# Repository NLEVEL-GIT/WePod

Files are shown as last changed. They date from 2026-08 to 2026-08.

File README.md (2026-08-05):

# WePod

Wepod is Our Ipod, it is an open source MP3 Player that uses the Xiao RP2040

PS: All images of the PCB, CAD and Schematics are on the assets folder if u wanna see.

## Features:
- 1.3 Inch TFT Display
- 5 Button
- SD Card Reader
- 3.5mm Jack
- Powered by any 5V Supply using the dedicated pads

## CAD Model:
Everything fits in a sandwich kind of way by stacking the bottom and top case parts and inbetween the PCB. It requires 4 M3x3 brass inserts and 4 15mm M3 Screws.
It has 3 different printed pieces. The Bottom part of the case where everything will sit in. The Top part that locks everything and the Butons (5 Needed).
Made in Fusion360 cuz its free.

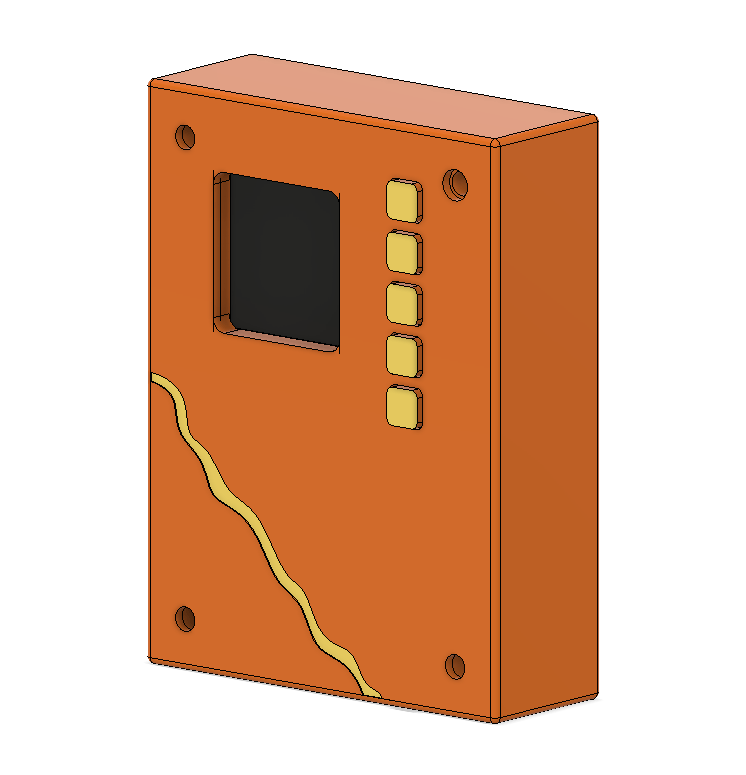
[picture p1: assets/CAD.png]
WePod 3D Render


## PCB
It was made in KiCad. Only needing to add Kicad Care package Symbols and Footprints for the Xiao RP2040 and a bunch of other symbols found in SnapEDA.
All 3D models were found on GrabCad

**Schematic:**
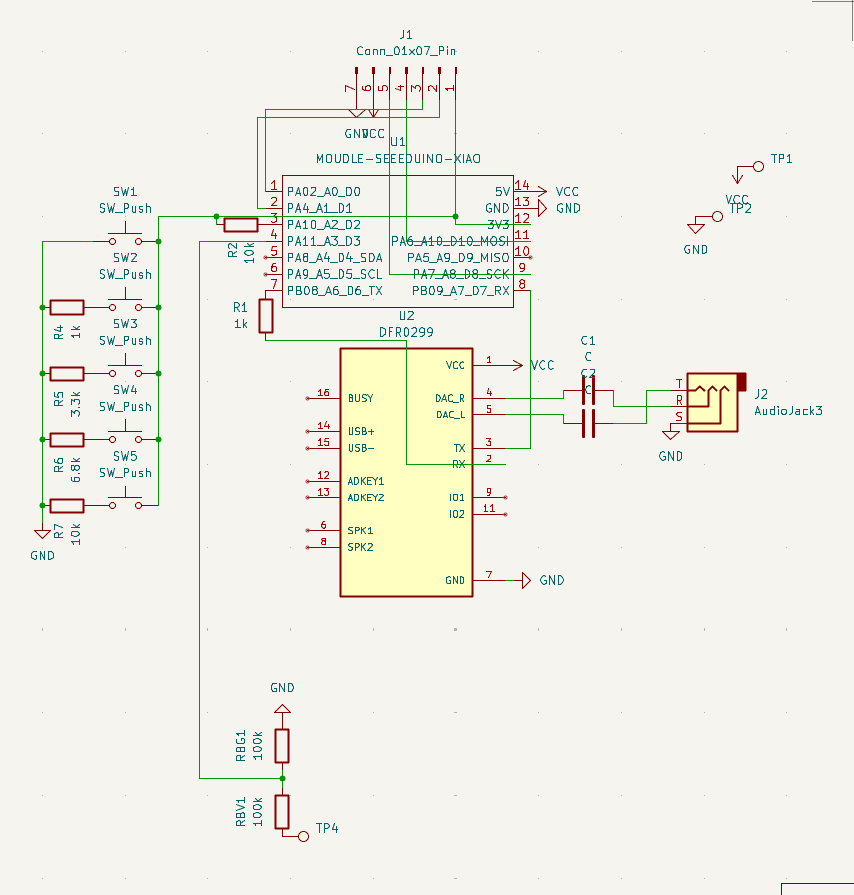
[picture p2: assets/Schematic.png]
WePod Schematic


**PCB Layout:**
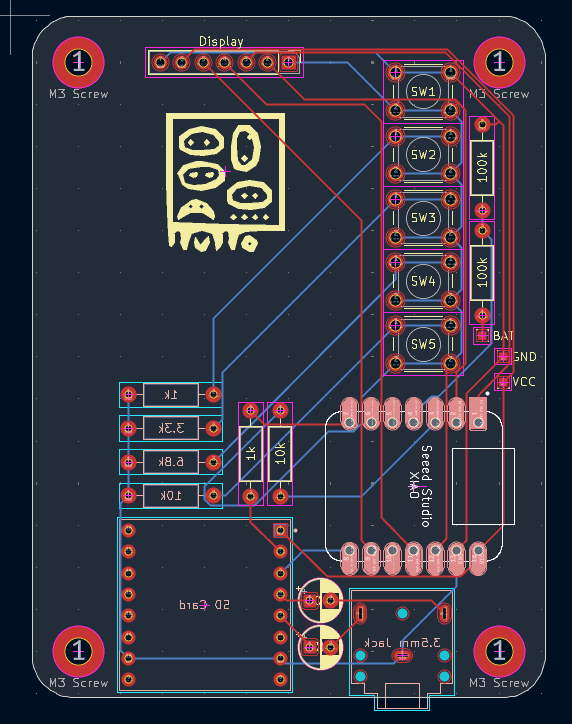
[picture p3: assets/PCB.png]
WePod PCB Layout


## Firmware Overview
The WePod uses C++ as its language of choice and it was made with the help of generative AI since im not really good at coding.

## BOM:
Here should be everything you need to make this hackpad

- 1.3 Inch TFT display
- DFPlayer
- 3.5mm Jack
- 5x 6x6mm buttons
- 1x XIAO RP2040
- 1x Case (3 printed parts)
- A Bunch of Resistors (1k, 3.3k, 6.8k, 10k and 100k)
- 2x 10uf Capacitors

## Extra stuff
This was my first Original project since my first was the MacroPad so not using a siplified code made me want to die. Conclusion: Hardware is life and coding Sucks

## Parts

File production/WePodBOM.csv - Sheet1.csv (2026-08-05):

Item Name | Qty | Price (total) (USD) (Conversion from Euro) | Item link | Notes
Seeed Studio Xiao RP2040 | 1 | $6.47 | https://mauser.pt | All items are from PT stores and have been converted from euro to dollar since I live in Portugal
1.3 Inch TFT Display | 1 | $5.22 | https://aliexpress.com
3.5mm Jack | 1 | $0.25 | https://www.digikey.pt
DFPlayer | 1 | $2.29 | https://aliexpress.com
Resistor Pack | 1 | $2,65 | https://aliexpress.com | This pack was choosen since it makes me save money by going over the necessary buy amount for the free shipping
10 uF Capacitors | 2 | $0.53 | https://mauser.pt | These were choosent since i only have 8mm of clearance between plates to fir the capacitors
6x6mm Buttons | 5 | $0.81 | https://mauser.pt
MH-CD42 + 5V Buck Converter | 1 | $2.48 | https://aliexpress.com | This price is the combined price of the actual product and its forced shipping of 1.45 euros since its a global seller
800mah Lipo battery | 1 | $6.58 | https://mauser.pt
Switch | 1 | $0.46 | https://www.aquario.pt
PCB | 1 | $5.11 | https://www.jlcpcb.com
Total Price (USD): | $30.20

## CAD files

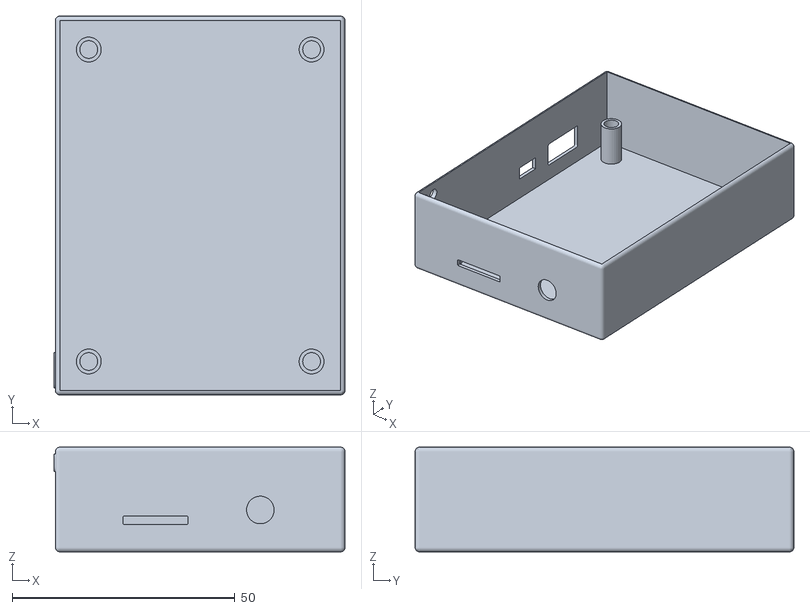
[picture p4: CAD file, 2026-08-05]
production/Bottom Case.stl
65.3 x 85.0 x 23.5

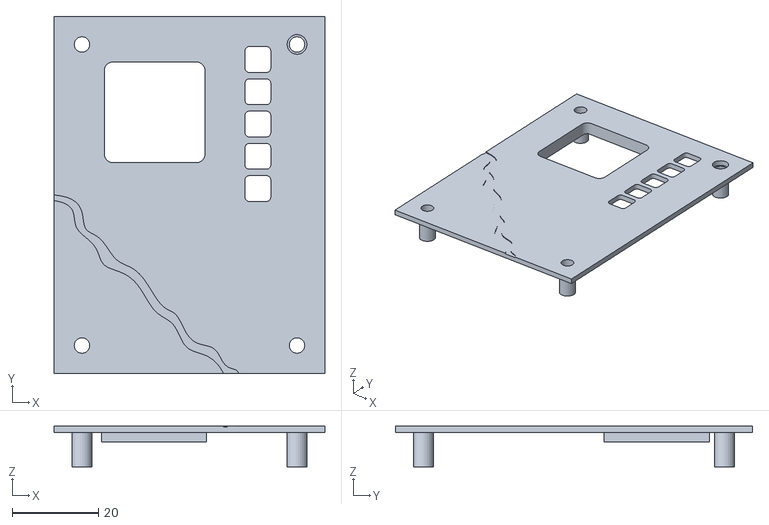
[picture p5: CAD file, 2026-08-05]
production/Top Case.stl
63.0 x 83.0 x 9.49

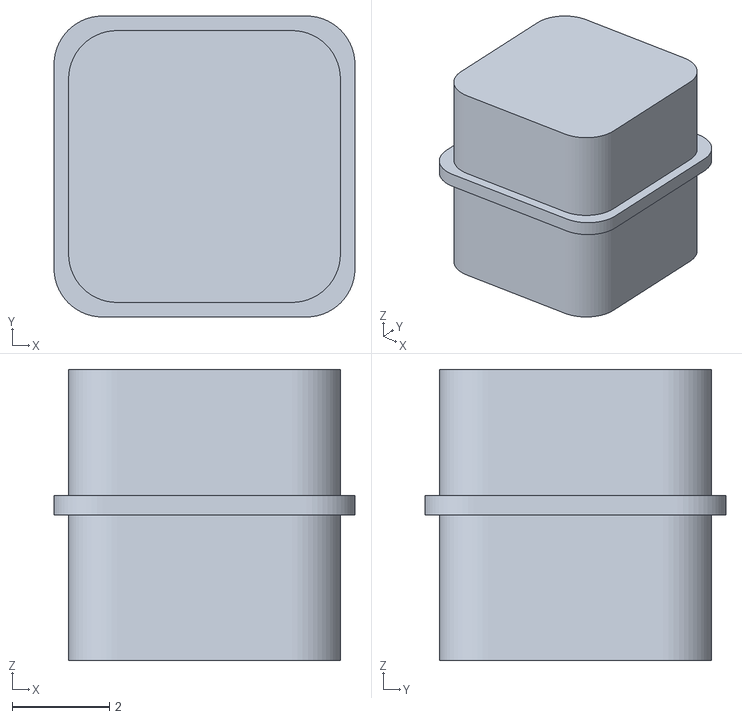
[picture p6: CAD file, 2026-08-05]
production/Button.stl
6.20 x 6.20 x 6.00

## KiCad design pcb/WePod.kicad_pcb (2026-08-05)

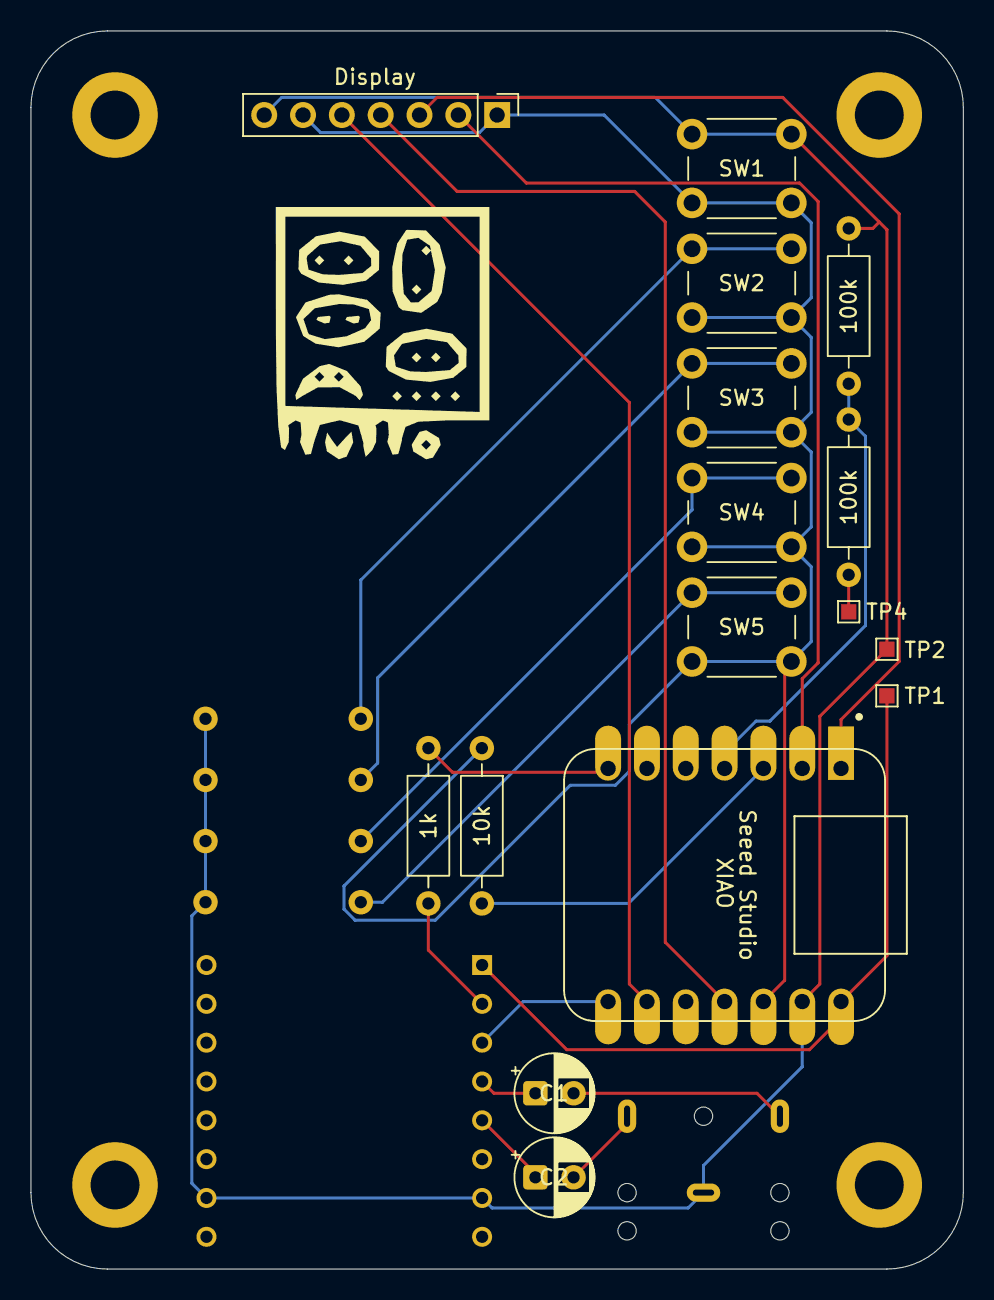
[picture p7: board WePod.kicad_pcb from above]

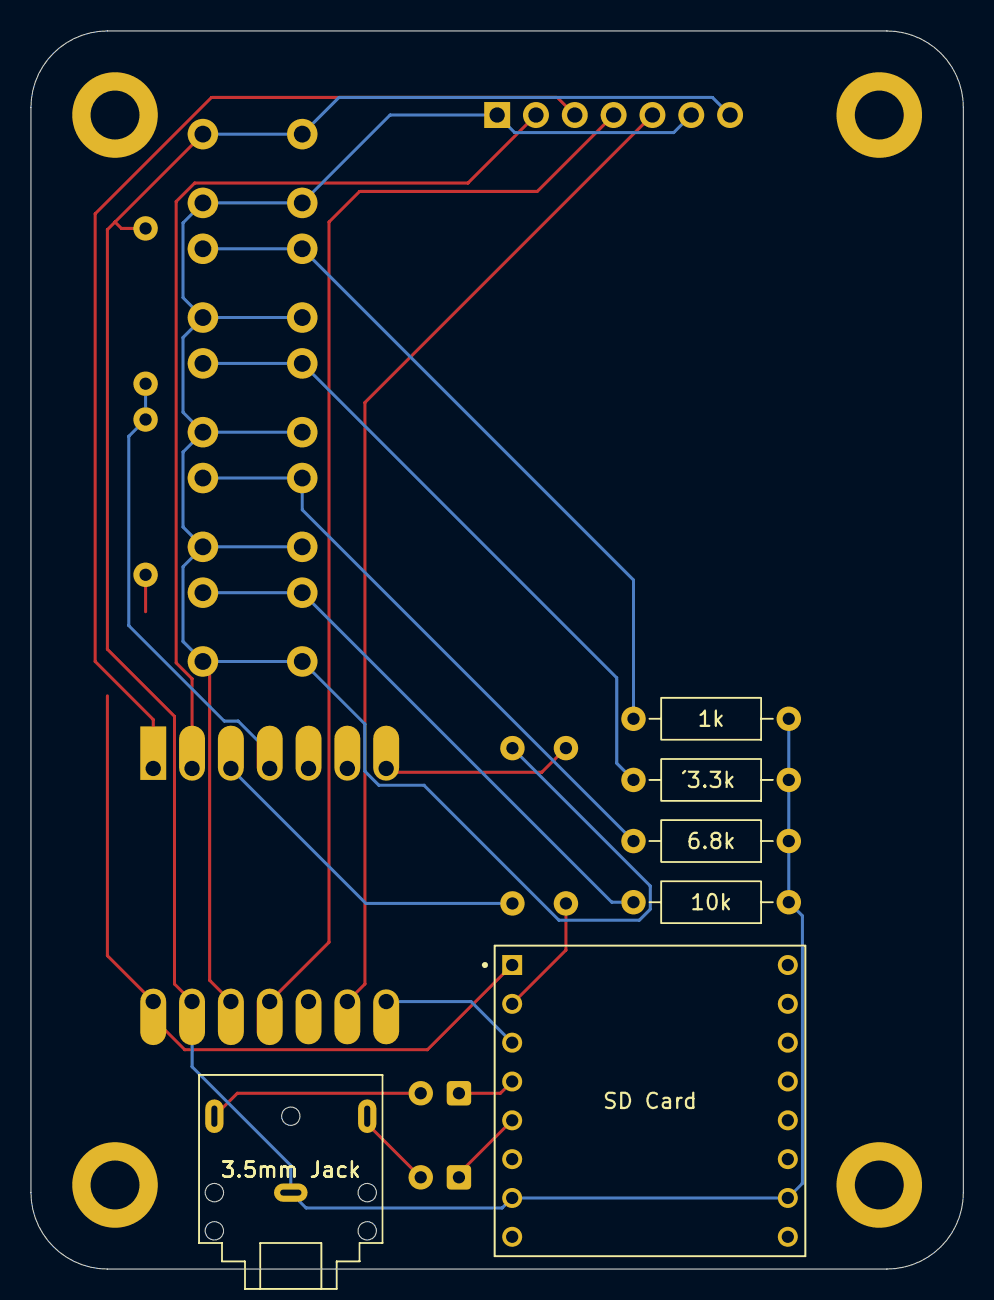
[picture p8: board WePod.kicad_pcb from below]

Board: 2 copper layers, 61.0 x 81.0 mm, 22 parts (6 on the bottom side), 21 nets.

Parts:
1k, 1k#2: 1k; R_Axial_DIN0207_L6.3mm_D2.5mm_P10.16mm_Horizontal
3.5mm Jack: 3.5mm Jack; Jack_3.5mm_CUI_SJ1-3523N_Horizontal
6.8k: 6.8k; R_Axial_DIN0207_L6.3mm_D2.5mm_P10.16mm_Horizontal
10k, 10k#2: 10k; R_Axial_DIN0207_L6.3mm_D2.5mm_P10.16mm_Horizontal
100k, 100k#2: 100k; R_Axial_DIN0207_L6.3mm_D2.5mm_P10.16mm_Horizontal
C1, C2: C; CP_Radial_D5.0mm_P2.50mm
J1: Display; PinHeader_1x07_P2.54mm_Vertical
SW1, SW2, SW3, SW4, SW5: SW_Push; SW_PUSH_6mm
TP1, TP2, TP4: TestPoint; TestPoint_Pad_1.0x1.0mm
U1: MOUDLE-SEEEDUINO-XIAO; XIAO-Generic-Hybrid-14P-2.54-21X17.8MM
U2: SD Card; MODULE_DFR0299
´3.3k: 3.3k; R_Axial_DIN0207_L6.3mm_D2.5mm_P10.16mm_Horizontal

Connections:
GND: 1k#2.1, 3.5mm Jack.S, 6.8k.1, 10k#2.1, 100k#2.2, J1.7, SW1.1, TP2.1 (1_1), U1.13 (GND), U2.7 (GND), U2.10 (GND), ´3.3k.1
unnamed: 3.5mm Jack.R, C1.2
unnamed: 3.5mm Jack.T, C2.2
unnamed: 10k.1, J1.1, J1.6, SW1.2, SW2.2, SW3.2, SW4.2, SW5.2, U1.12 (3V3)
unnamed: J1.2, U1.2 (PA4_A1_D1)
unnamed: J1.3, U1.1 (PA02_A0_D0)
unnamed: J1.4, U1.11 (PA6_A10_D10_MOSI)
unnamed: J1.5, U1.9 (PA7_A8_D8_SCK)
unnamed: 1k#2.2, SW2.1
unnamed: SW3.1, ´3.3k.2
unnamed: 6.8k.2, SW4.1
unnamed: 10k#2.2, SW5.1
unnamed: 100k.1, TP4.1 (1_1)
unnamed: 10k.2, U1.3 (PA10_A2_D2)
unnamed: 100k.2, 100k#2.1, U1.4 (PA11_A3_D3)
unnamed: 1k.1, U1.7 (PB08_A6_D6_TX)
unnamed: U1.8 (PB09_A7_D7_RX), U2.3 (TX)
unnamed: C2.1, U2.5 (DAC_L)
unnamed: C1.1, U2.4 (DAC_R)
unnamed: 1k.2, U2.2 (RX)
VCC: TP1.1 (1_1), U1.14 (5V), U2.1 (VCC)

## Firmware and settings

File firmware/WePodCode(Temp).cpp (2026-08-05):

#include <Arduino.h>                //If the code breaks sry i cant code well and gemini helped a bunch so blame it on him
#include <DFRobotDFPlayerMini.h>
#include <TFT_eSPI.h> 

const int PIN_BTN_LADDER = A2;   
const int PIN_BATTERY_ADC = A3;  

const int VAL_SELECT   = 100; //change this crap when i get the actual stuff cuz resistors are funny 
const int VAL_DOWN     = 300; //change this crap when i get the actual stuff cuz resistors are funny 
const int VAL_UP       = 500; //change this crap when i get the actual stuff cuz resistors are funny  
const int VAL_VOL_UP   = 700; //change this crap when i get the actual stuff cuz resistors are funny 
const int VAL_VOL_DOWN = 900; //change this crap when i get the actual stuff cuz resistors are funny 
const int ADC_TOLERANCE = 50; //change this crap when i get the actual stuff cuz resistors are funny  

enum Button { BTN_NONE, BTN_SELECT, BTN_DOWN, BTN_UP, BTN_VOL_UP, BTN_VOL_DOWN }; //No Digital Situation

TFT_eSPI tft = TFT_eSPI(); 
DFRobotDFPlayerMini myDFPlayer;

Button currentButton = BTN_NONE;
Button lastButton = BTN_NONE;
unsigned long lastDebounceTime = 0;
const int debounceDelay = 50; 
unsigned long selectPressTimer = 0; 

bool inMenuMode = true; 
bool isPlaying = false;
int currentVolume = 15; 
unsigned long lastBatteryCheck = 0;
int currentBatteryPercent = 0;

int currentFolderIndex = 1;  
int currentSongIndex = 1;    
int selectedListItem = 0;    

// Content Setup 
String folderName = "FOLDER 01";
const int numSongsInFolder = 2; 
String songNames[numSongsInFolder] = {"SONG A", "SONG B"};

Button getPressedButton() {
  int val = analogRead(PIN_BTN_LADDER);
  if (abs(val - VAL_SELECT) < ADC_TOLERANCE)   return BTN_SELECT;
  if (abs(val - VAL_DOWN) < ADC_TOLERANCE)     return BTN_DOWN;
  if (abs(val - VAL_UP) < ADC_TOLERANCE)       return BTN_UP;
  if (abs(val - VAL_VOL_UP) < ADC_TOLERANCE)   return BTN_VOL_UP;
  if (abs(val - VAL_VOL_DOWN) < ADC_TOLERANCE) return BTN_VOL_DOWN;
  return BTN_NONE; 
}

void setup() {
  Serial.begin(115200);
  
  randomSeed(micros()); //Gambling

  tft.init();
  tft.setRotation(1); 
  tft.fillScreen(TFT_BLACK);
  tft.setTextColor(TFT_WHITE, TFT_BLACK); 
  tft.setTextSize(2);
  tft.setCursor(10, 10);
  tft.println("Booting OS...");

  Serial1.begin(9600);
  if (!myDFPlayer.begin(Serial1)) {
    tft.setTextColor(TFT_RED, TFT_BLACK);
    tft.println("Audio Error!");
    while(true); 
  }

  myDFPlayer.volume(currentVolume);
  updateScreenUI(); 
}

void loop() {

  Button reading = getPressedButton();
  Button pressedThisFrame = BTN_NONE; 

  if (reading != lastButton) lastDebounceTime = millis();
  if ((millis() - lastDebounceTime) > debounceDelay) {
    if (reading != currentButton) {
      currentButton = reading;
      if (currentButton != BTN_NONE) pressedThisFrame = currentButton;
    }
  }
  lastButton = reading;

  if (currentButton == BTN_SELECT && !inMenuMode) {            // Too lazy for 6th button
    if (selectPressTimer == 0) selectPressTimer = millis();
    if (millis() - selectPressTimer > 1000) { 
      inMenuMode = true; 
      selectPressTimer = 0; 
      updateScreenUI();
    }
  } else {
    selectPressTimer = 0; 
  }

  if (inMenuMode) {
    if (pressedThisFrame == BTN_SELECT) {
      inMenuMode = false; 
      currentSongIndex = selectedListItem + 1; 
      myDFPlayer.playFolder(currentFolderIndex, currentSongIndex);
      isPlaying = true;
      updateScreenUI();
    }
    if (pressedThisFrame == BTN_DOWN && selectedListItem < numSongsInFolder - 1) {
      selectedListItem++;
      updateScreenUI();
    }
    if (pressedThisFrame == BTN_UP && selectedListItem > 0) {
      selectedListItem--;
      updateScreenUI();
    }
  } 

  else {
    if (pressedThisFrame == BTN_SELECT) {
      isPlaying = !isPlaying;
      if (isPlaying) myDFPlayer.start();
      else myDFPlayer.pause();
      updateScreenUI(); 
    }
    if (pressedThisFrame == BTN_DOWN && currentSongIndex < numSongsInFolder) {
      currentSongIndex++;
      myDFPlayer.playFolder(currentFolderIndex, currentSongIndex);
      isPlaying = true;
      updateScreenUI();
    }
    if (pressedThisFrame == BTN_UP && currentSongIndex > 1) {
      currentSongIndex--;
      myDFPlayer.playFolder(currentFolderIndex, currentSongIndex);
      isPlaying = true;
      updateScreenUI();
    }
  }

  if (pressedThisFrame == BTN_VOL_UP && currentVolume < 30) {
    currentVolume++;
    myDFPlayer.volume(currentVolume);
    updateScreenUI(); 
  }
  if (pressedThisFrame == BTN_VOL_DOWN && currentVolume > 0) {
    currentVolume--;
    myDFPlayer.volume(currentVolume);
    updateScreenUI();
  }

  if (millis() - lastBatteryCheck > 10000) {  //battery cuz i wanna use it outside my house
    checkBattery();
    lastBatteryCheck = millis();
    updateScreenUI(); 
  }
}

void checkBattery() {
  int rawValue = analogRead(PIN_BATTERY_ADC);
  float pinVoltage = (rawValue / 4095.0f) * 3.3f;
  float batteryVoltage = pinVoltage * 2.0f;
  currentBatteryPercent = constrain((int)map((int)(batteryVoltage * 100.0f), 330, 420, 0, 100), 0, 100);
  currentBatteryPercent = constrain(currentBatteryPercent, 0, 100);
}

void updateScreenUI() {
  int screenW = tft.width();
  int screenH = tft.height();

  tft.fillRect(0, 0, screenW, 35, TFT_DARKGREY); 
  tft.setTextSize(2);
  tft.setCursor(10, 10);
  
  if (isPlaying) {
    tft.setTextColor(TFT_GREEN, TFT_DARKGREY);
    tft.print("▶ "); 
  } else {
    tft.setTextColor(TFT_YELLOW, TFT_DARKGREY);
    tft.print("II ");
  }
  tft.setTextColor(TFT_WHITE, TFT_DARKGREY);
  tft.print(" Vol: ");
  tft.print(currentVolume);
  tft.print("      Bat: "); 
  tft.print(currentBatteryPercent);
  tft.print("%");

  tft.fillRect(0, 35, screenW, screenH - 35, TFT_BLACK); 
  
  if (inMenuMode) {
    tft.setTextColor(TFT_WHITE, TFT_BLACK);
    tft.setTextSize(3);
    tft.setCursor(10, 50);
    tft.print(folderName);

    tft.setTextSize(2); 
    int startY = 90; 
    int spacing = 35; 

    for (int i = 0; i < numSongsInFolder; i++) {
      tft.setCursor(20, startY + (i * spacing)); 
      if (i == selectedListItem) {
        tft.setTextColor(TFT_GREEN, TFT_BLACK); 
        tft.print("└─ ");
        tft.print(songNames[i]);
        
        // Draw the arrow on the right side
        tft.setCursor(screenW - 50, startY + (i * spacing));
        tft.print("<-"); 
      } else {
        tft.setTextColor(TFT_WHITE, TFT_BLACK); 
        tft.print("└─ ");
        tft.print(songNames[i]);
      }
    }
  } 
  else {
    tft.setTextColor(TFT_WHITE, TFT_BLACK);
    tft.setTextSize(3);
    
    int textX = (screenW - (songNames[currentSongIndex - 1].length() * 18)) / 2;
    if (textX < 0) textX = 10;
    tft.setCursor(textX, 60);
    tft.print(songNames[currentSongIndex - 1]); 

    // vinyl aka cooler cd
    int cx = screenW / 2; 
    int cy = 150; 
    int outerRadius = 40;
    int innerRadius = 15;
    
    // Generate a random color for vinyl aka GAMBLING
    uint16_t randomColor = random(0xFFFF);

    tft.fillCircle(cx, cy, outerRadius, TFT_DARKGREY); 
    tft.fillCircle(cx, cy, innerRadius, randomColor); 
    tft.fillCircle(cx, cy, 4, TFT_BLACK);              
  }
}

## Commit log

2026-08-05 Added the actual stuff
    [Bottom Case.stl, Button.stl, Top Case.stl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]
2026-08-05 Create WePodBOM.csv - Sheet1.csv
    [WePodBOM.csv - Sheet1.csv]
2026-08-05 Update WePodBOM.csv - Sheet1.csv
    [WePodBOM.csv - Sheet1.csv]
2026-08-05 Edited an Error on the 3.3v line in the pcb
    [WePod.kicad_pcb, WePod.kicad_sch]
2026-08-05 Update Bottom Case.stl
    [Bottom Case.stl]
